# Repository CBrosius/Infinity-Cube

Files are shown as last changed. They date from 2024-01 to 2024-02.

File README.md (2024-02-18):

This is a fork of the Infinity-Cube project by [s-marlex](https://github.com/s-marley/Infinity-Cube) (or see below)

In my project, there are a few things changed.

1. The included 3D-Printfiles are scaled to 171x171x171mm
 - This allows them to be printed perfectly on a Prusa Mini or a Bambulab A1 Mini
 - The needed mirrors are exactly 150x150mm, which is easier to buy
 - The grow in size should allow the use of standard 144LED/m Strips that are much more cheaper than the original ones
   (e.g. https://de.aliexpress.com/item/2036819167.html )
   This results in 20LEDs per Strut
 - The standard LED-Strips provide a "natural" seal for the mirrors an hopefully hold them in place automatically
 - I extended the Base, to create place for the controller-electronics (was a separate Box in the the original project)
2. The Cube is no longer cut in half, instead the top is alone and the struts are complete at the bottom part
 - I hope this will make the assembly easier.
3. Instead of creating a custom binary for the electroics I use standard [WLED](https://kno.wled.ge/)

---

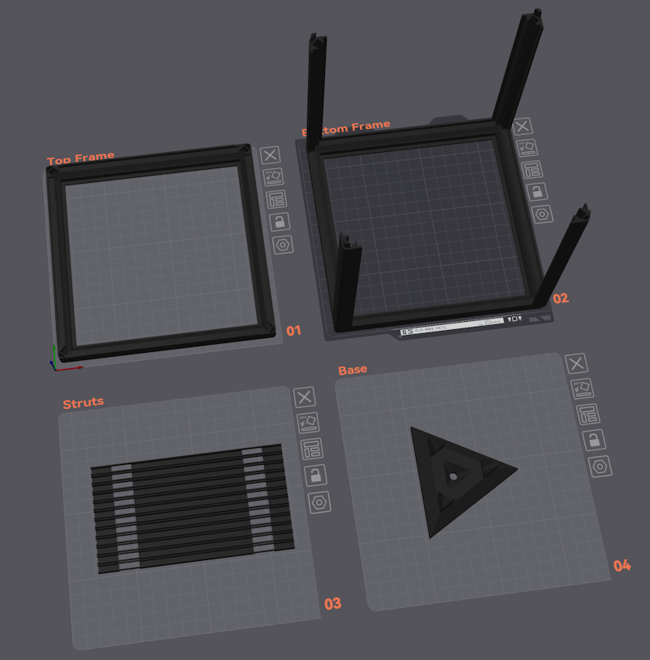
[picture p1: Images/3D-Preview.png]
PrintPlate-View


---

With the new Cube-Parameters I changed the wiring in the Schematics
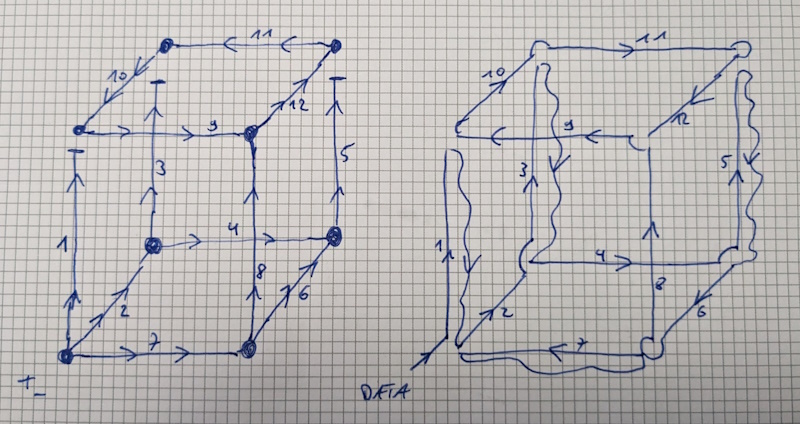
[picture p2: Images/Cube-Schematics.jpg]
Schematic


On the left side, there is the wiring of the power-lines (VCC + GND), on the right side the new data-wiring.

---

The LED-Strips are cut every 20 LEDs. To be able to do all soldering on the backside of the strip I removed the double-sided tape where the cutouts in the struts are.
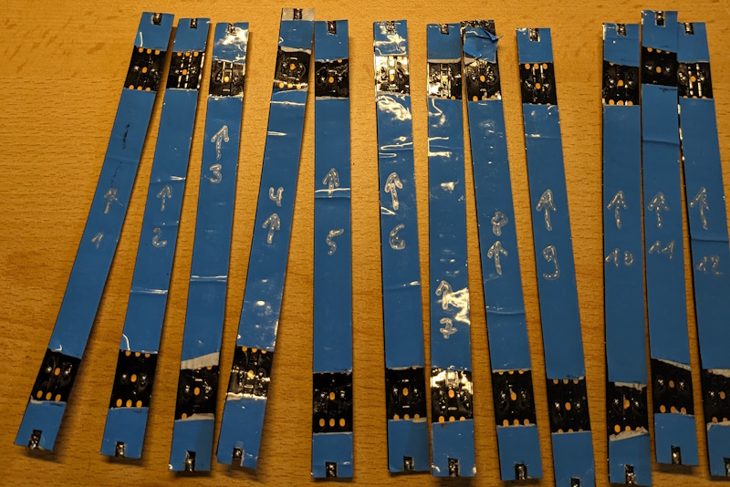
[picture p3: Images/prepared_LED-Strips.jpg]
prepared LED-Strips


Then I presoldered the PADs for + and - to make it easier to wire them later
As the Data-PADs were very small, I scraped away the protective varnish with a scalpel and presoldered them, too.

---

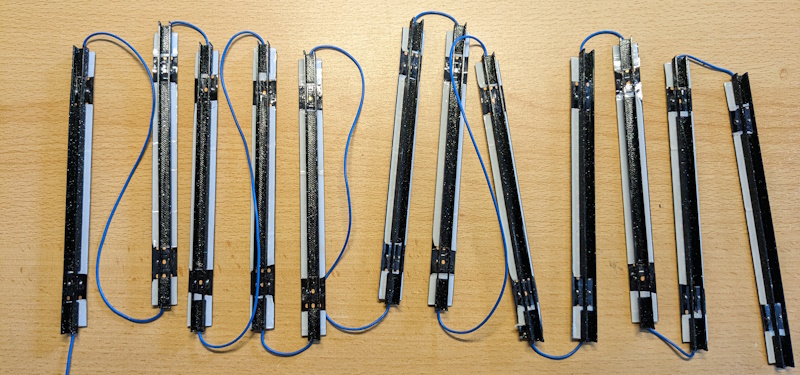
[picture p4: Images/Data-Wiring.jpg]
Data-Wiring


---

To have a starting point in WLED, here is a screenshot of some basic setting that works out of the box

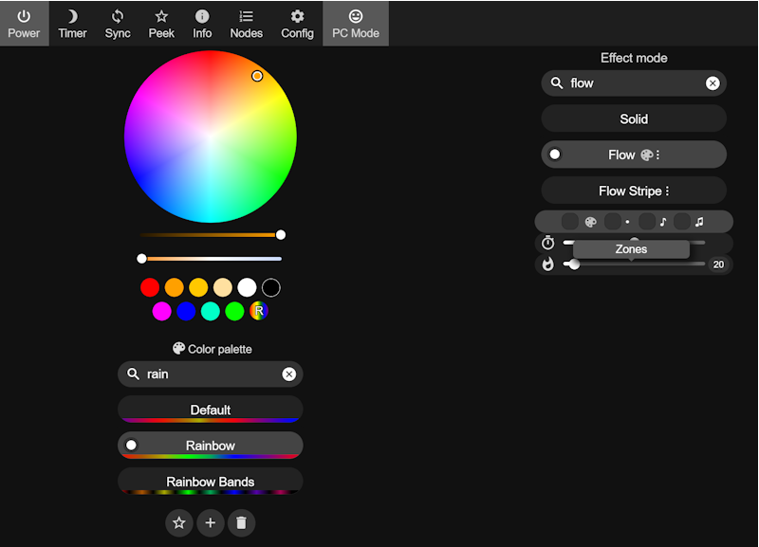
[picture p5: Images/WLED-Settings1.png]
WLED-Settings


---
---

Original project
https://github.com/s-marley/Infinity-Cube

YouTube Video
LED Cube (https://www.youtube.com/watch?v=gbqNV-nmTS4)

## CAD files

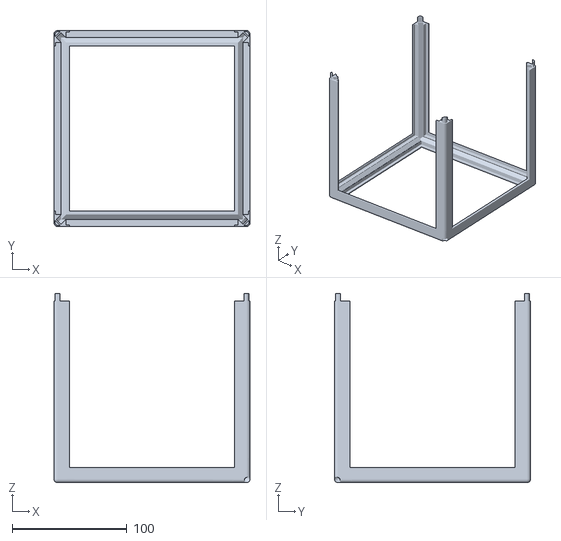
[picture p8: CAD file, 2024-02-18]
3D-Print/Cube-Bottom.stl
171.0 x 171.0 x 165.2

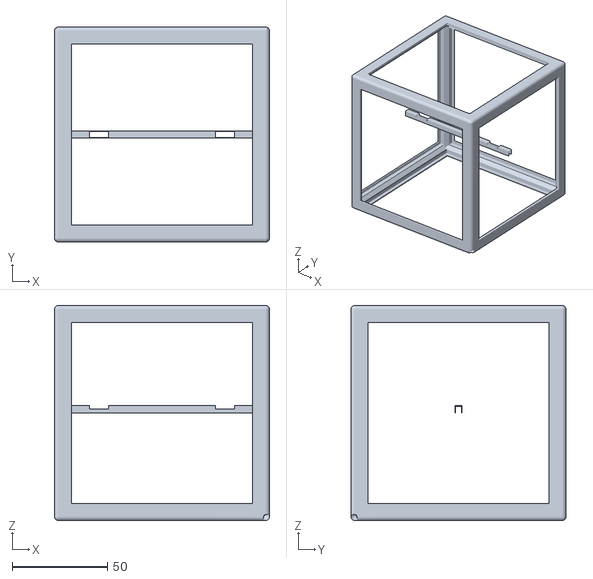
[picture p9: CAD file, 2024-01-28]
Fusion360/LEDCube - Modified v4.stl
112.7 x 112.7 x 112.7

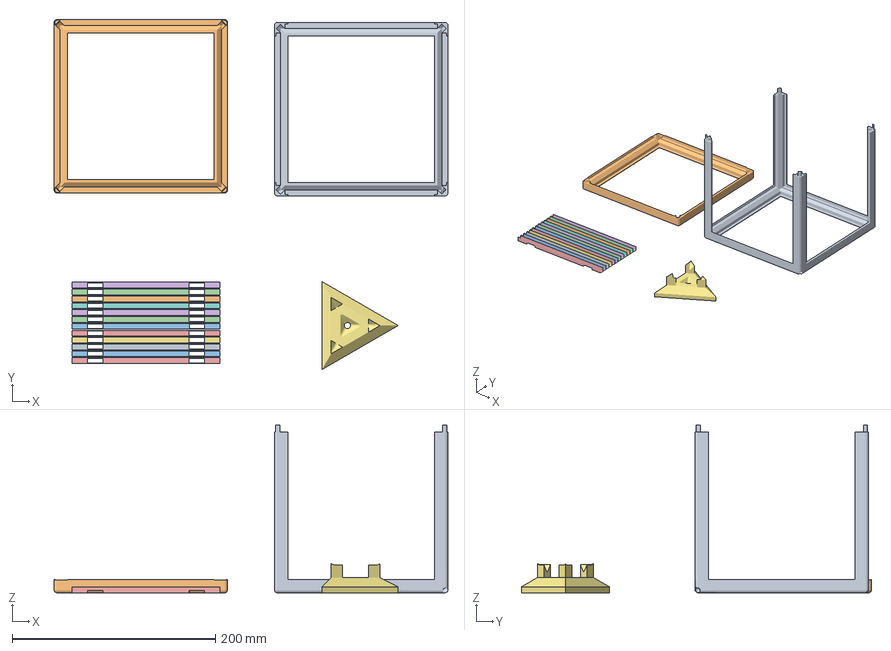
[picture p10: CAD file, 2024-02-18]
3D-Print/Cube modified.3mf
388.1 x 344.8 x 165.2 mm
LEDCube - Modified v4.stl_1
LEDCube - Modified v4.stl_2
LEDCube - Modified v4.stl_3 x 12
Stand_modified.stl

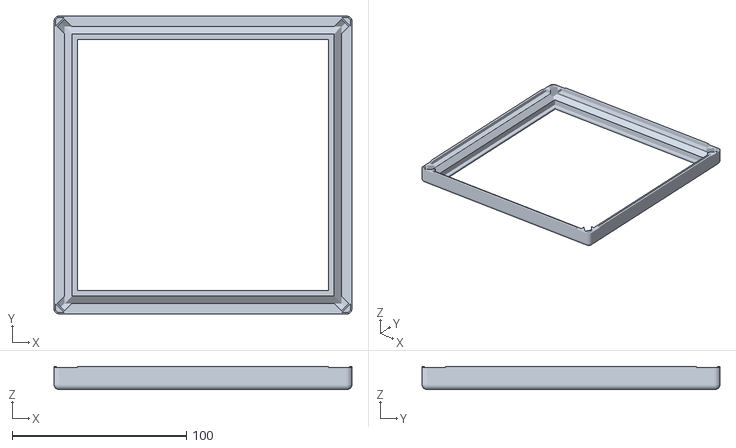
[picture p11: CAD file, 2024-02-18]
3D-Print/Cube-Top.stl
171.0 x 171.0 x 13.4

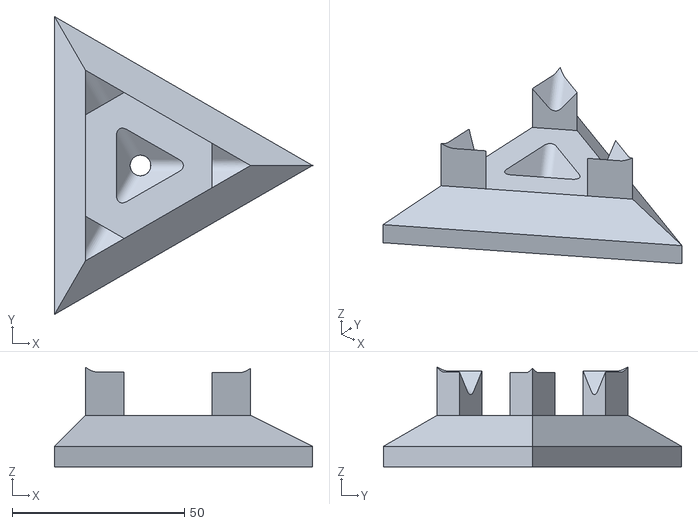
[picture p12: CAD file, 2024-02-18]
3D-Print/Stand_modified.stl
75.0 x 86.6 x 29.0

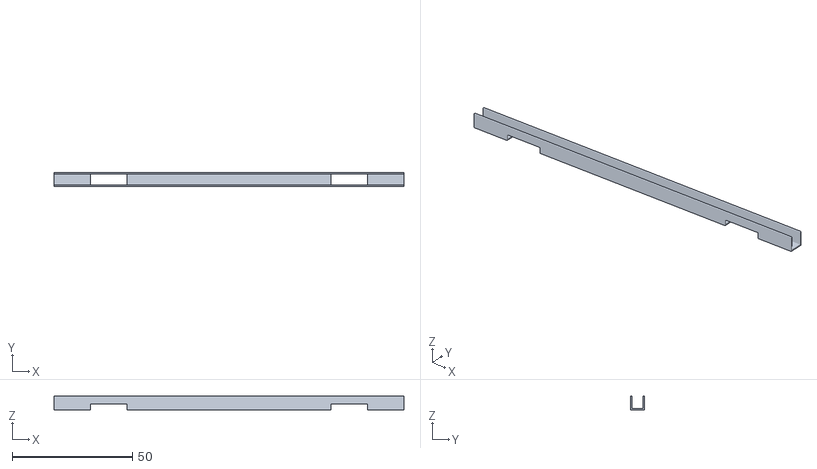
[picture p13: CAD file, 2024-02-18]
3D-Print/Cube-Strut.stl
145.7 x 5.77 x 5.77

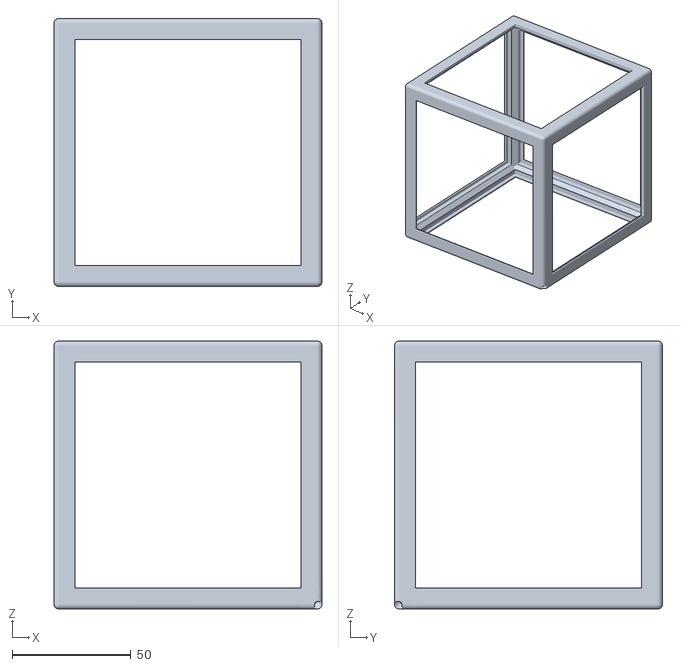
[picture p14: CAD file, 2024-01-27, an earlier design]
Fusion360/LEDCube - Modified v2.stl
112.7 x 112.7 x 112.7

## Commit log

2024-01-27 add modified Cube-STL
    [LEDCube - Modified v2.stl]
2024-01-27 add scaled 3D-Print Projectfile
    [Cube modified.3mf]
2024-01-28 Fixed connector-length
    [LEDCube - Modified v4.stl]
2024-02-18 upload new files
    [Cube modified.3mf, Cube-Bottom.stl, Cube-Strut.stl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]
